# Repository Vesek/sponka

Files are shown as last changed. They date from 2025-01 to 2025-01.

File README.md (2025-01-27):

[English README](/README_en.md)
# sponka
RGB sponka na vlasy, postavená na flex PCB
### ***velice work in progress***
## Komponenty
- CH32V003
	- velice low-cost MCU, dostatečné na ovládání LED
	- chtěl jsem se s ním naučit
- WS2812B-MINI
	- Menší verze WS2812B
- TP4057
	- Nabíječ baterie s ochranou
	- můžete znát z většiny Li-ion nabíjecích desek z Aliexpressu
- DW01A
	- Ochrana samotné baterie
	- Některé baterie mají vestavěné, pro ostatní je zde
## Software
Software je napsaný s vývojovým prostředím [ch32v003fun](https://github.com/cnlohr/ch32v003fun) - open-source a lightweight stack pro programování těchto čipů

### Programování desky
Na desce jsou vyvedeny 3 piny pro SWIO. Výrobce čipu se bohužel rozhodl zavést
nestandardní "spin-off" SWD, takže potřebujete kompatibilní programátor.

Mimo oficiálního programátoru existují i SW programátory na různé MCU, některé lze najít v README [ch32v003fun](https://github.com/cnlohr/ch32v003fun),
existují ale i verze pro [Flipper Zero](https://github.com/sukvojte/wch_swio_flasher)a [RPi Pico](https://github.com/aappleby/picorvd).

Zapojení jednotlivých programátorů můžete najít v jejich README a
pinout SWIO je napsaný na spodní straně desky.

Software zkompilujete a nahrajete pomocí:
```bash
make
```
Nezapoměňte před tím stáhnout submoduly:
```bash
git submodule update --init
```

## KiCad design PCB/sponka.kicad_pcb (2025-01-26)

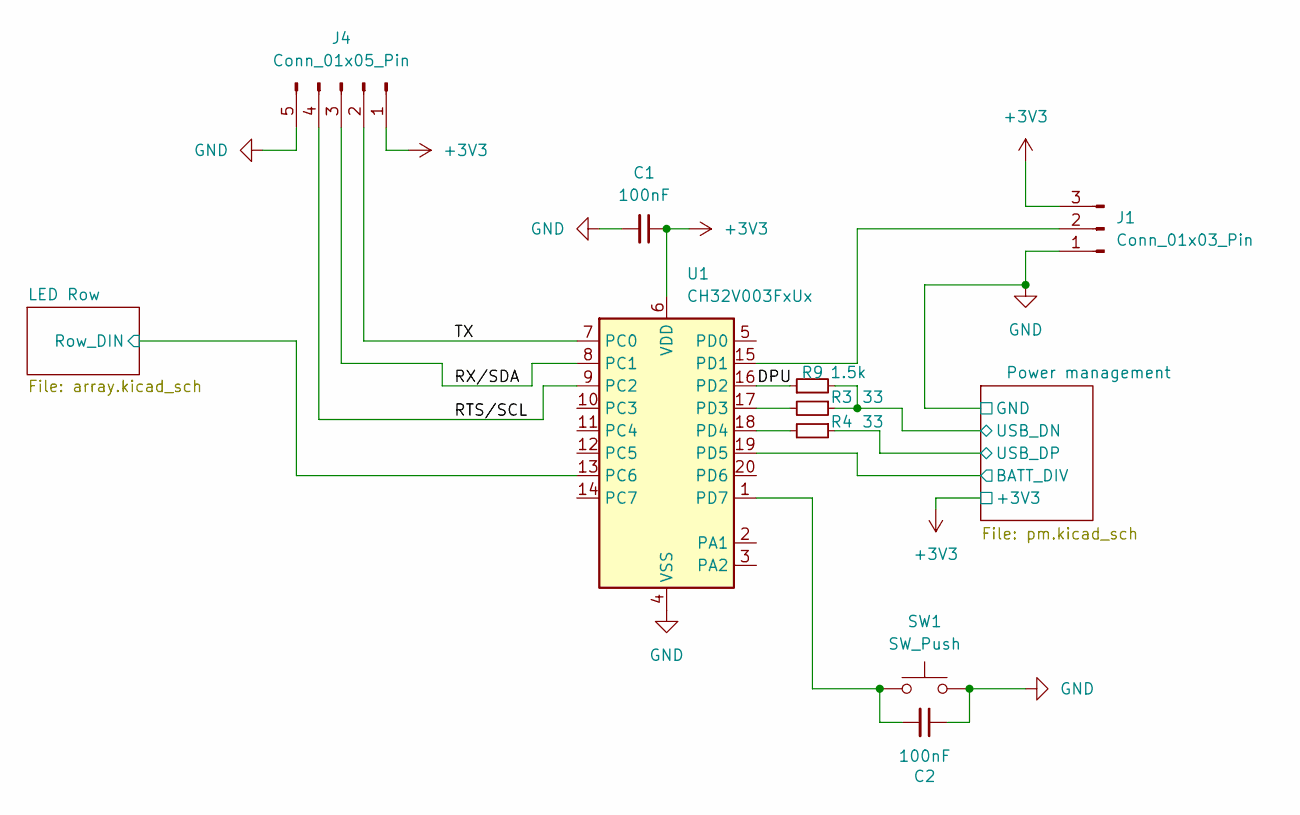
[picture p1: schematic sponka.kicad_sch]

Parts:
C1, C2: 100nF; C_0402_1005Metric
J1: Conn_01x03_Pin; pogo_pins_1_3
J4: Conn_01x05_Pin; pogo_pins_1_5
R3, R4: 33; R_0402_1005Metric
R9: 1.5k; R_0402_1005Metric
SW1: SW_Push; SW_SPST_B3U-1000P
U1: CH32V003FxUx; QFN-20-1EP_3x3mm_P0.4mm_EP1.65x1.65mm_ThermalVias

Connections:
+3V3: C1.1, J1.3, J4.1, U1.6 (VDD); also elsewhere on the board
/DPU: R9.1, U1.16 (PD2)
/LED Row/Row_DIN: U1.13 (PC6); also elsewhere on the board
/Power management/BATT_DIV: U1.19 (PD5); also elsewhere on the board
/Power management/USB_DN: R3.1, R9.2; also elsewhere on the board
/Power management/USB_DP: R4.1; also elsewhere on the board
/RTS/SCL: J4.4, U1.9 (PC2)
/RX/SDA: J4.3, U1.8 (PC1)
/TX: J4.2, U1.7 (PC0)
GND: C1.2, C2.1, J1.1, J4.5, SW1.2, U1.4 (VSS), U1.21 (VSS); also elsewhere on the board
unnamed: J1.2, U1.15 (PD1)
unnamed: R3.2, U1.17 (PD3)
unnamed: R4.2, U1.18 (PD4)
unnamed: C2.2, SW1.1, U1.1 (PD7)

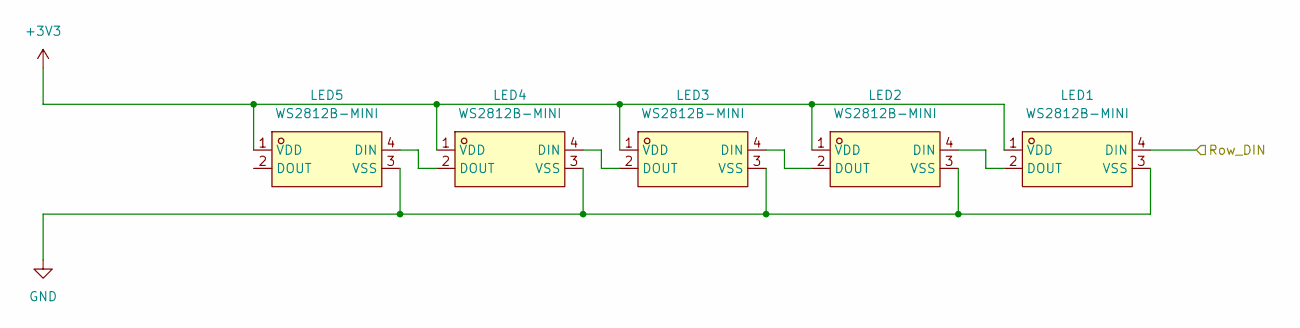
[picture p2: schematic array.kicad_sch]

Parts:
LED1, LED2, LED3, LED4, LED5: WS2812B-MINI; LED-SMD_4P-L3.5-W3.5-TL_WS2812B; LCSC Part C527089

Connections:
+3V3: LED1.1 (VDD), LED2.1 (VDD), LED3.1 (VDD), LED4.1 (VDD), LED5.1 (VDD); also elsewhere on the board
/LED Row/Row_DIN: LED1.4 (DIN); also elsewhere on the board
GND: LED1.3 (VSS), LED2.3 (VSS), LED3.3 (VSS), LED4.3 (VSS), LED5.3 (VSS); also elsewhere on the board
unnamed: LED1.2 (DOUT), LED2.4 (DIN)
unnamed: LED2.2 (DOUT), LED3.4 (DIN)
unnamed: LED3.2 (DOUT), LED4.4 (DIN)
unnamed: LED4.2 (DOUT), LED5.4 (DIN)

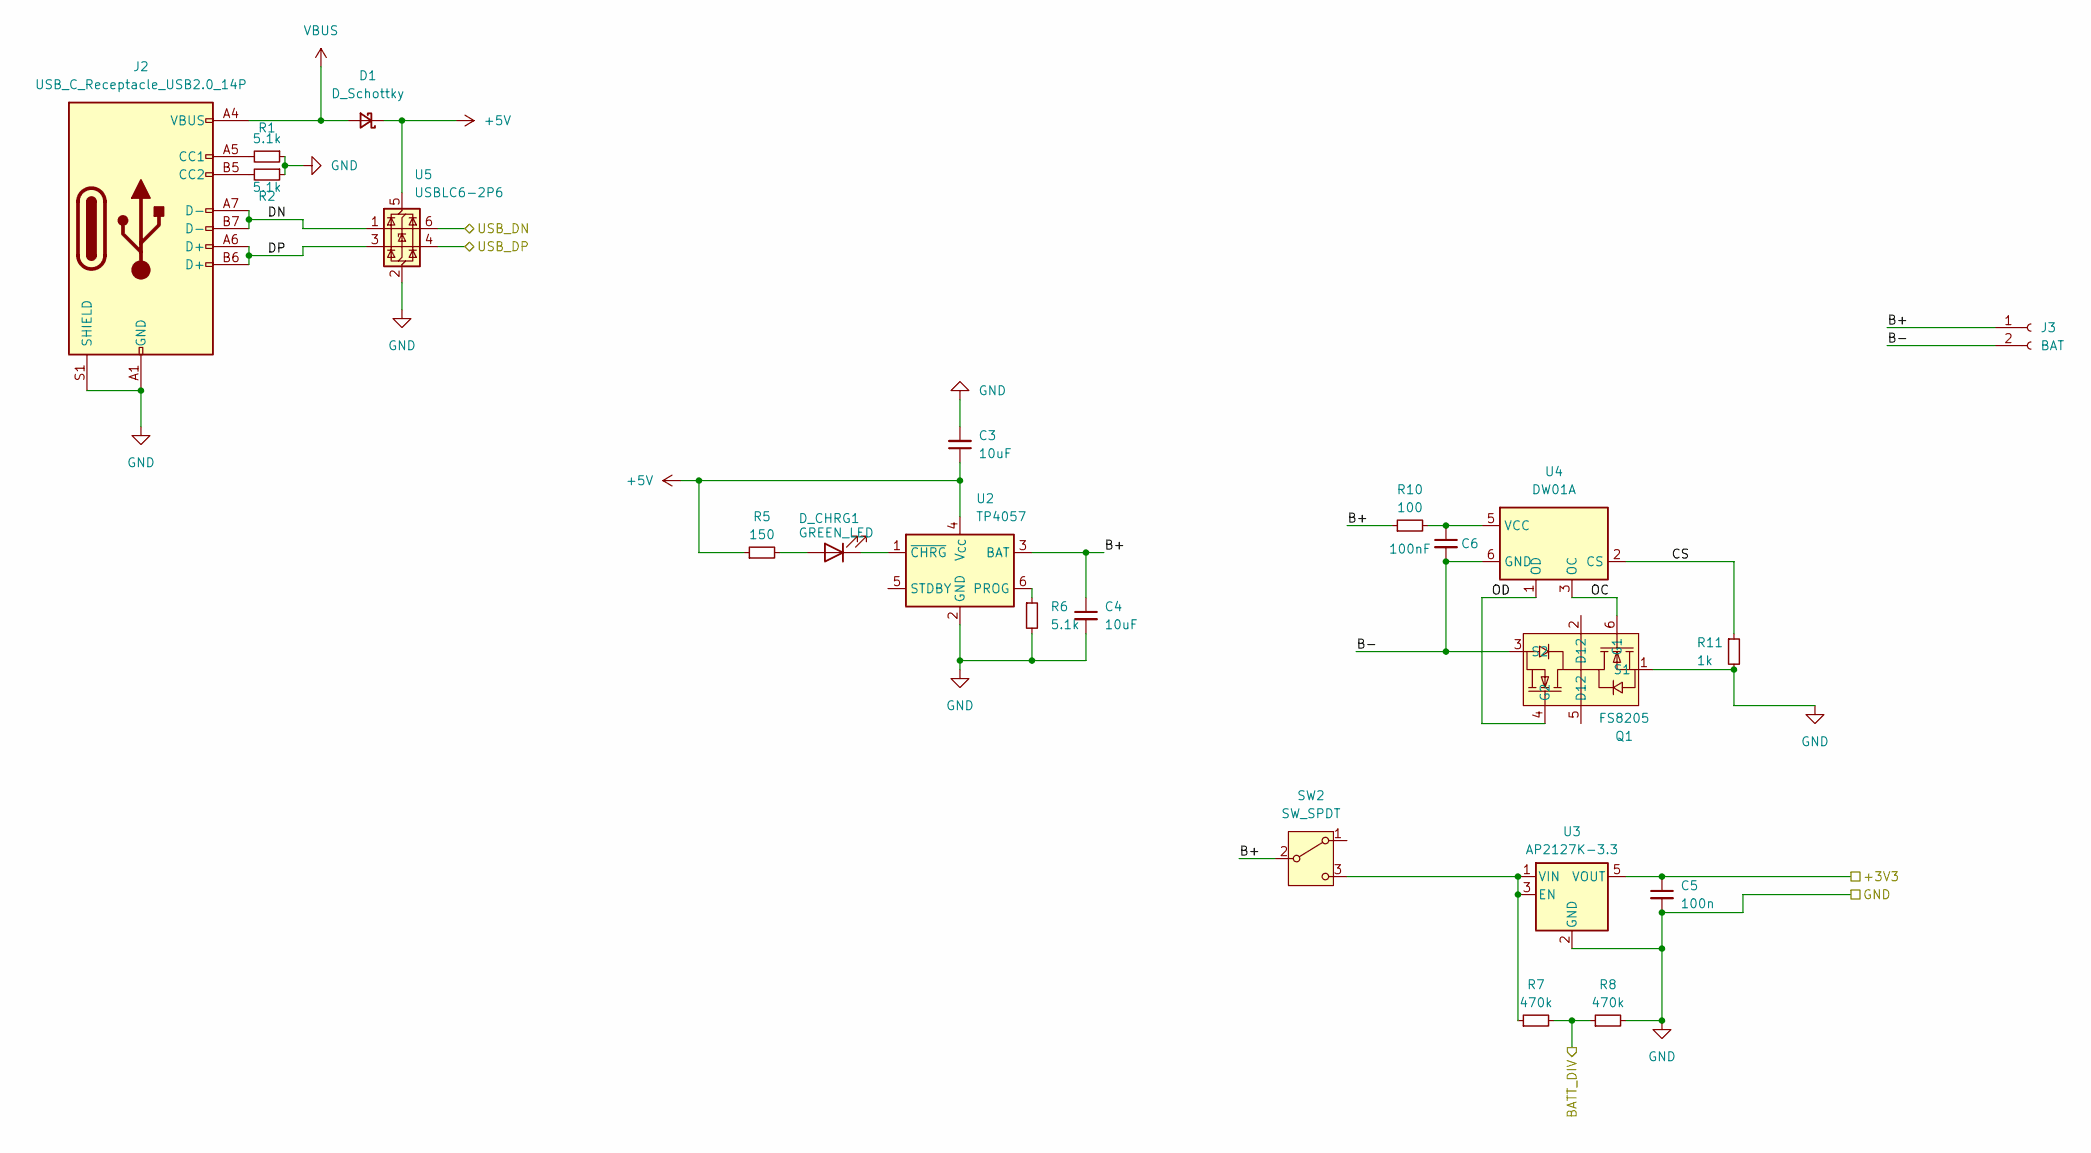
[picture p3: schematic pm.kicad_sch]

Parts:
C3, C4: 10uF; C_0402_1005Metric
C5: 100n; C_0402_1005Metric
C6: 100nF; C_0402_1005Metric
D1: D_Schottky; D_0402_1005Metric
D_CHRG1: GREEN_LED; LED_0603_1608Metric
J2: USB_C_Receptacle_USB2.0_14P; USB_C_Receptacle_G-Switch_GT-USB-7010ASV
J3: BAT; JST_SH_SM02B-SRSS-TB_1x02-1MP_P1.00mm_Horizontal
Q1: FS8205; SOT-23-6; LCSC Part C32254
R1, R2, R6: 5.1k; R_0402_1005Metric
R5: 150; R_0402_1005Metric
R7, R8: 470k; R_0402_1005Metric
R10: 100; R_0402_1005Metric
R11: 1k; R_0402_1005Metric
SW2: SW_SPDT; SW_SPDT_PCM12
U2: TP4057; TSOT-23-6
U3: AP2127K-3.3; SOT-23-5
U4: DW01A; SOT-23-6
U5: USBLC6-2P6; SOT-666

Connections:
+3V3: C5.1, U3.5 (VOUT); also elsewhere on the board
+5V: C3.1, D1.1 (K), R5.1, U2.4 (V_{CC}), U5.5 (VBUS)
/Power management/B+: C4.1, J3.1, R10.1, SW2.2 (B), U2.3 (BAT)
/Power management/B-: C6.2, J3.2, Q1.3 (S2), U4.6 (GND)
/Power management/BATT_DIV: R7.2, R8.1; also elsewhere on the board
/Power management/CS: R11.1, U4.2 (CS)
/Power management/DN: J2.A7 (D-), J2.B7 (D-), U5.1 (I/O1)
/Power management/DP: J2.A6 (D+), J2.B6 (D+), U5.3 (I/O2)
/Power management/OC: Q1.6 (G1), U4.3 (OC)
/Power management/OD: Q1.4 (G2), U4.1 (OD)
/Power management/USB_DN: U5.6 (I/O1); also elsewhere on the board
/Power management/USB_DP: U5.4 (I/O2); also elsewhere on the board
GND: C3.2, C4.2, C5.2, J2.A1 (GND), J2.A12 (GND), J2.B1 (GND), J2.B12 (GND), J2.S1 (SHIELD), Q1.1 (S1), R1.1, R2.1, R6.2, R8.2, R11.2, U2.2 (GND), U3.2 (GND), U5.2 (GND); also elsewhere on the board
unnamed: D_CHRG1.2 (A), R5.2
unnamed: D_CHRG1.1 (K), U2.1 (~CHRG)
unnamed: J2.A5 (CC1), R1.2
unnamed: J2.B5 (CC2), R2.2
unnamed: R7.1, SW2.3 (C), U3.1 (VIN), U3.3 (EN)
unnamed: R6.1, U2.6 (PROG)
unnamed: C6.1, R10.2, U4.5 (VCC)
VBUS: D1.2 (A), J2.A4 (VBUS), J2.A9 (VBUS), J2.B4 (VBUS), J2.B9 (VBUS)

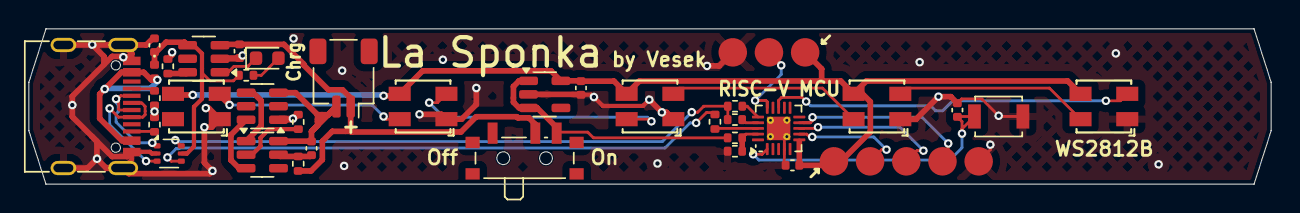
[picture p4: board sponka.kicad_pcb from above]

Board: 2 copper layers, 87.2 x 10.9 mm, 36 parts (0 on the bottom side), 34 nets.

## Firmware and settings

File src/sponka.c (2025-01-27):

#include "ch32v003fun.h"
#include <stdbool.h>

#define WS2812DMA_IMPLEMENTATION
#define WSGRB // For SK6805-EC15
#define N_LEDS 5
#include "ws2812b_dma_spi_led_driver.h"

#include "ch32v003_GPIO_branchless.h"

#include "modes.h"

#define N_MODES (sizeof(sponka_modes) / sizeof((sponka_modes)[0]))

bool skip_frametime = false;
uint8_t mode = 0;

void EXTI7_0_IRQHandler( void ) __attribute__((interrupt));
void EXTI7_0_IRQHandler( void )
{
    skip_frametime = true;
    mode = (mode + 1) % N_MODES;
    EXTI->INTFR = 0xffffffff;
}

// Callbacks that you must implement.
uint32_t WS2812BLEDCallback( int ledno )
{
    return sponka_modes[mode].get_pixel();
}

int main()
{
	SystemInit();

	// Init button
	GPIO_port_enable(GPIO_port_D);
	GPIO_pinMode(GPIOv_from_PORT_PIN(GPIO_port_D, 7), GPIO_pinMode_I_pullUp, GPIO_Speed_In);

	RCC->APB2PCENR |= RCC_AFIOEN;

	// assign pin 7 interrupt from portD (0b11) to EXTI channel 2
	AFIO->EXTICR |= (uint32_t)(0b11 << (2*7));

	// enable line2 interrupt event
	EXTI->INTENR |= EXTI_Line7;
	EXTI->FTENR |= EXTI_Line7;

	NVIC_EnableIRQ( EXTI7_0_IRQn );

	WS2812BDMAInit( );

	uint32_t targend = SysTick->CNT + Ticks_from_Ms(sponka_modes[mode].frametime);
	while (true){
	    if (skip_frametime || (((int32_t)( SysTick->CNT - targend )) > 0)){
			targend = SysTick->CNT + Ticks_from_Ms(sponka_modes[mode].frametime);

            skip_frametime = false;

            WS2812BDMAStart( N_LEDS );

            while( WS2812BLEDInUse );
		}
	}

	return 0;
}

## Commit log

2024-09-05 Made first PCB
    [array.kicad_sch, pm.kicad_sch, sponka.kicad_pcb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]
2024-09-06 PCB V2
    [array.kicad_sch, pm.kicad_sch, sponka.kicad_pcb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]
2024-09-07 New PCB design
    [sponka.kicad_pcb]
2024-09-07 New PCB revision
    [pm.kicad_sch, sponka.kicad_pcb]
2024-09-08 Probably the final update
    [sponka.kicad_pcb, sponka.kicad_sch]
2024-09-08 Small updates to PCB
    [sponka.kicad_pcb]
2024-09-10 Made smol :) Anyway, this is just WIP, still working on it
    [array.kicad_sch, sponka.kicad_pcb]
2024-09-10 Progress update
    [pm.kicad_sch, sponka.kicad_pcb, sponka.kicad_sch]
2024-09-11 Probably done?
    [sponka.kicad_pcb]
2024-09-12 Add battery connector 3D models
2024-09-12 New design WIP
    [array.kicad_sch, sponka.kicad_pcb]
2024-09-12 Ma favorite design yet!
    [pm.kicad_sch, sponka.kicad_pcb]
2024-09-12 Update silkscreen
    [sponka.kicad_pcb]
2024-09-13 Update the backside
    [pm.kicad_sch, sponka.kicad_pcb]
2024-09-14 Change the battery connector resolve issues
    [pm.kicad_sch, sponka.kicad_pcb]
2024-09-18 Add battery protection circuit
    [pm.kicad_sch]
2024-09-18 Add protection circuit to PCB I don't like the design tho, so let's fix that
    [pm.kicad_sch, sponka.kicad_pcb]
2024-12-20 Add USBLC6-2P6 for ESD protection The usual COMPLETE REDESIGN because it didn't fit
    [pm.kicad_sch, sponka.kicad_pcb, sponka.kicad_sch]
2024-12-20 Replace 5k with 5.1k resistor Resistor for limiting charging current, it is within tolerance - eliminating one SKU
    [pm.kicad_sch, sponka.kicad_pcb]
2024-12-20 Small polishing touches Move vias out of the way of silkscreen and vice versa
    [sponka.kicad_pcb]
2024-12-24 Change LED resistor value
    [pm.kicad_sch, sponka.kicad_pcb]
2024-12-28 Update PCB
    [sponka.kicad_pcb]
2024-12-28 Change LED and it's resistor Once again, i found i had this laying around
    [pm.kicad_sch, sponka.kicad_pcb]
2025-01-26 Fix wrong values
    [sponka.kicad_pcb, sponka.kicad_sch]
